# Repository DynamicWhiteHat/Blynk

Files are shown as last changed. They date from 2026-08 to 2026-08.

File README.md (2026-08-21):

# Blynk
A feature-rich LED controller

> [!NOTE]
> This board runs on [WLED firmware](https://kno.wled.ge/)

## Features:
- Powered by an ESP32 S3
- ICS-43434 microphone
- Plus line-in with ES7243
- Low-profile PIR for motion detection
- IR receiver with custom remote control
- BH1750 ambient light sensor
- Full RGBW CCT support
- Reverse polarity protection and automatic supply switching

## Image Gallery:
<table align="center">
  <tr>
    <td align="center">
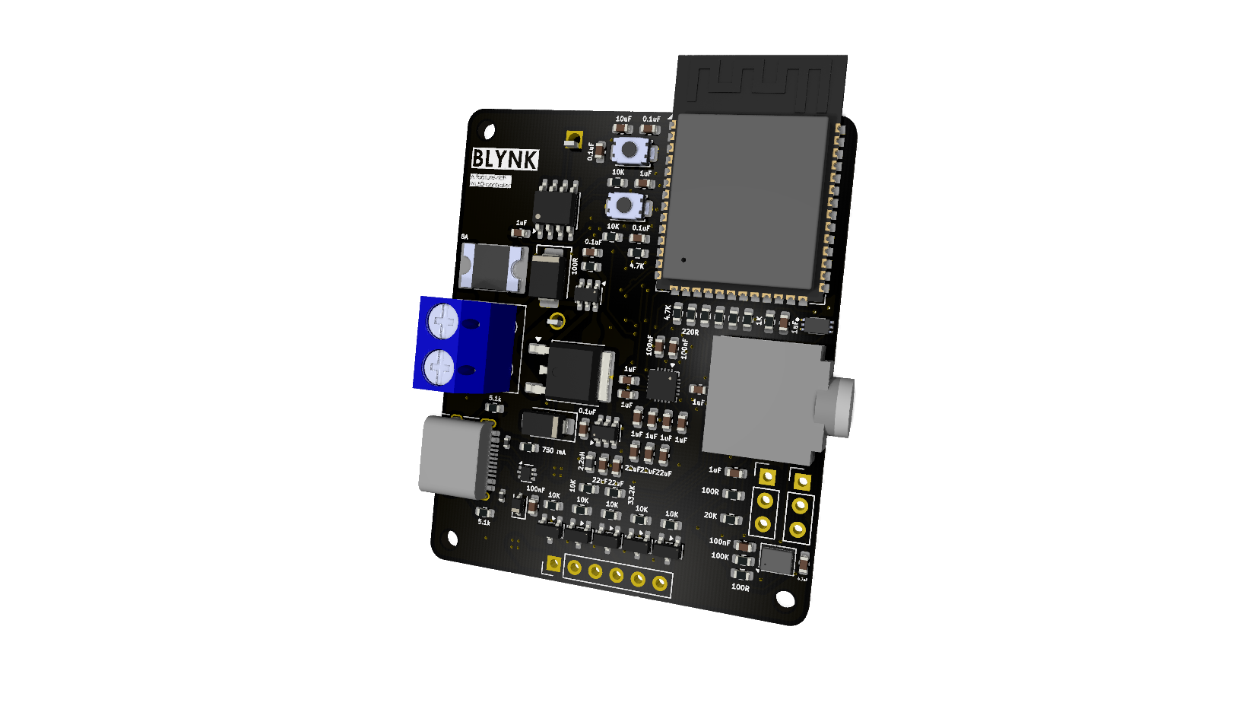
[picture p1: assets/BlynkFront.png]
      
    </td>
    <td align="center">
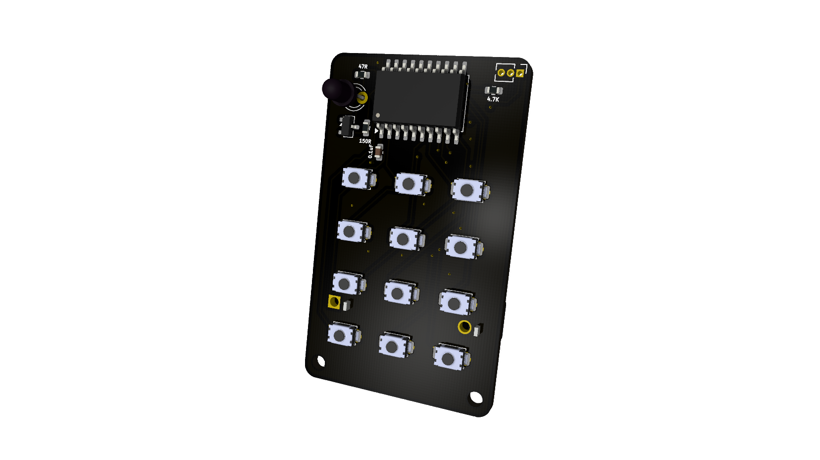
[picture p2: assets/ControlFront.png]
      
    </td>
  </tr>
  <tr>
    <td align="center" colspan="2">
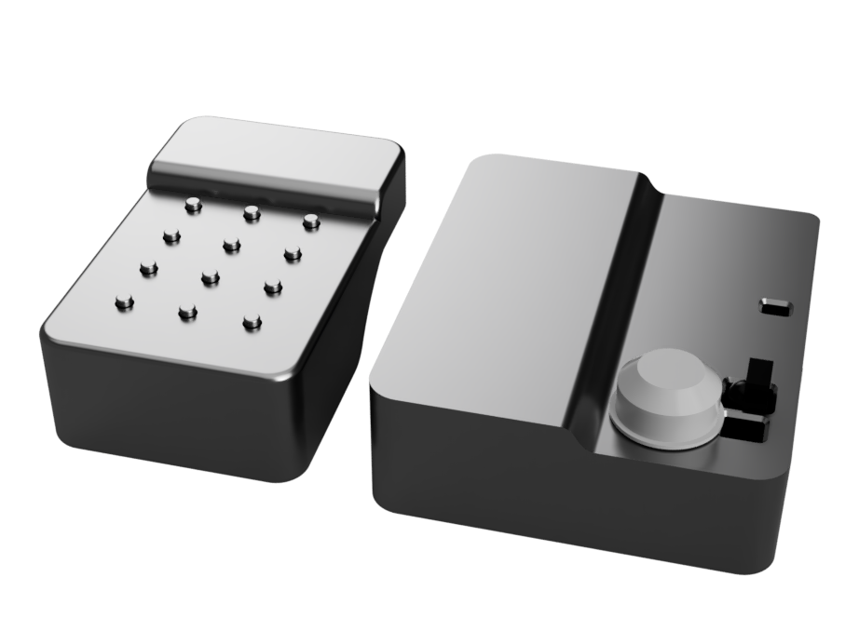
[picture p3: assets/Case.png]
      
    </td>
  </tr>
</table>

## Why I Designed This Project:
I began this project because I am getting a new large table built in my room and would love some LED lighting under it. I decided to make myself an LED controller with a lot of features. Most importantly, I wanted to have it be compatible with Alexa to match the other lights in my room. After a quick search, I found that the WLED firmware accomplishes all that I want: it is feature-rich, Alexa compatible, and supports custom ESP32 boards. And so, I embarked on a quest to make the most feature-packed LED controller to exist.

## Schematics And PCBs:
<table align="center">
  <tr>
    <td align="center" colspan="2">
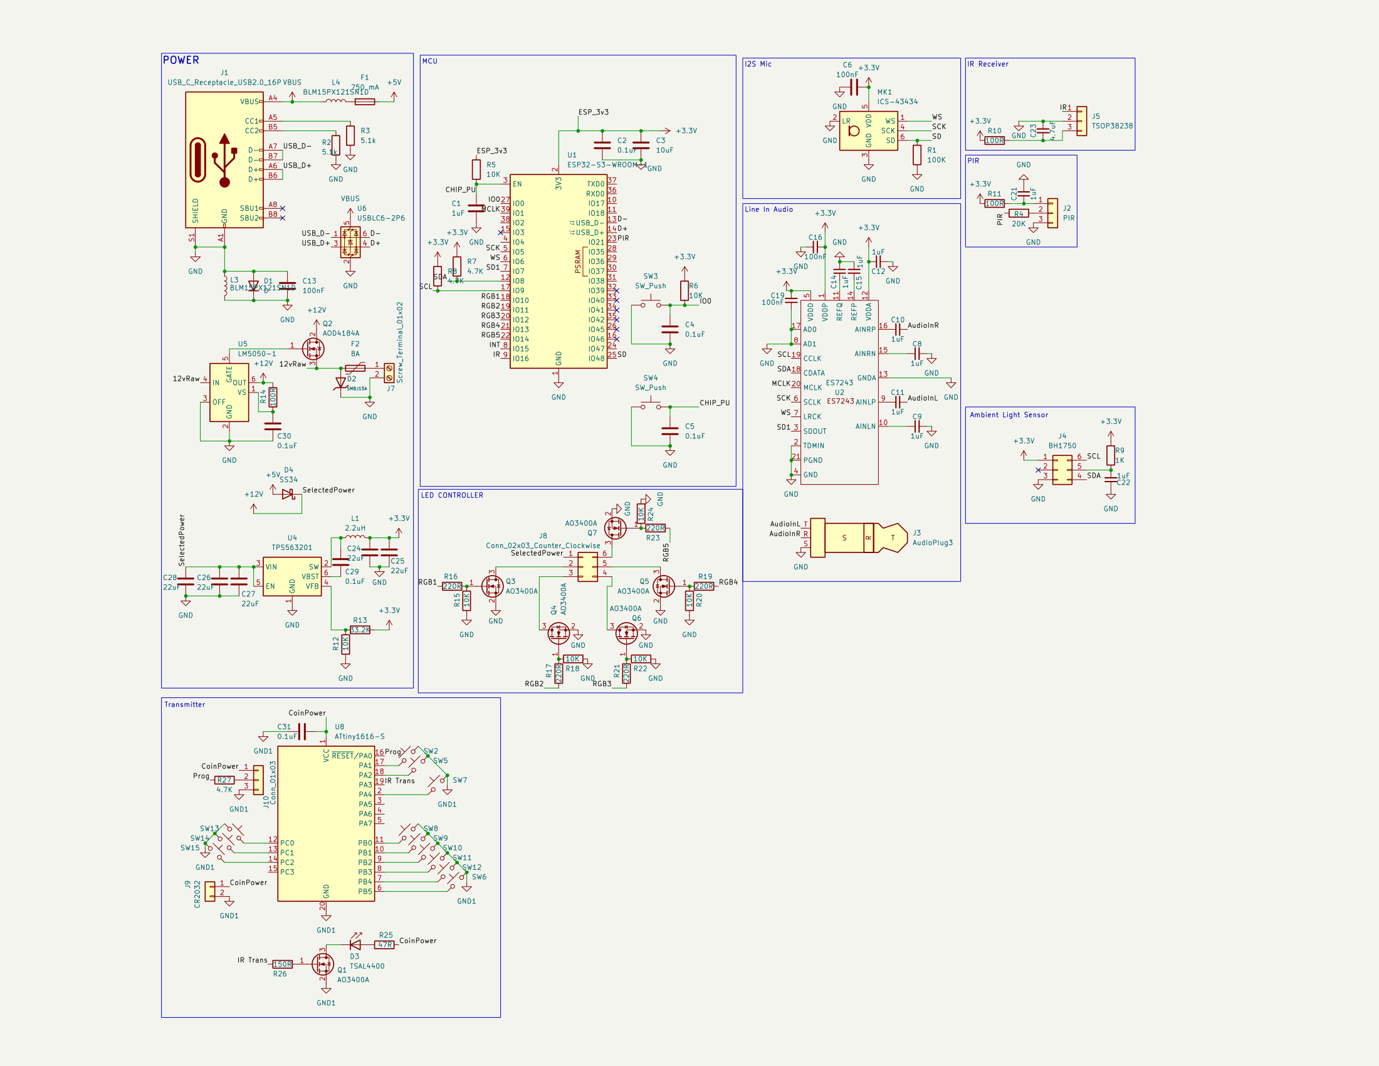
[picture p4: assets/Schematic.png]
      
    </td>
  </tr>
  <tr>
     <td align="center">
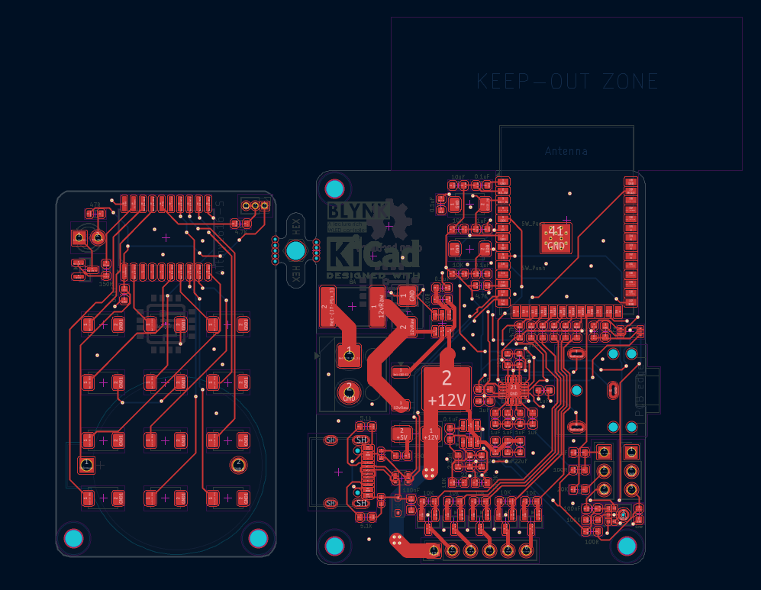
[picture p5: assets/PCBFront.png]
      
    </td>
    <td align="center">
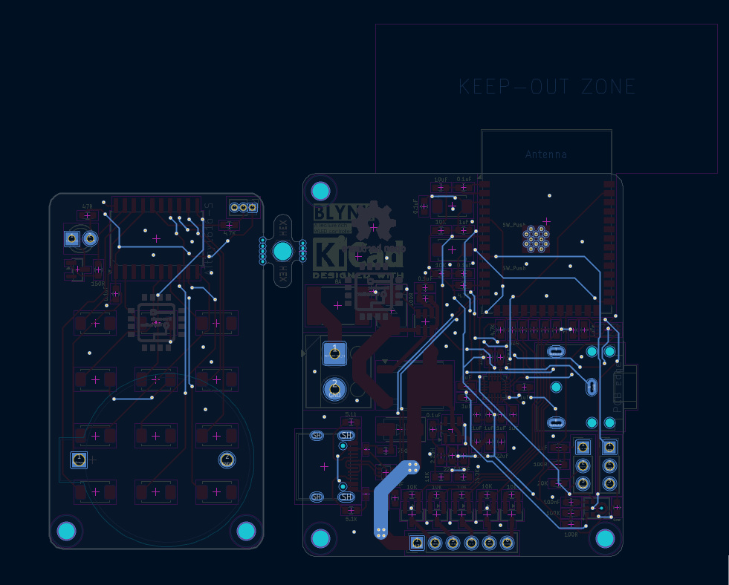
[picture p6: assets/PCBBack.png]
      
    </td>
  </tr>
</table>

## Usage:
Follow the instructions on the [WLED getting started page](https://kno.wled.ge/basics/getting-started/) after assembling your PCB to get it running.

## BOM:
|Part |Quantity |Price |Link | | | | |
|---|---|---|---|---|---|---|---|
|PCB+Stencil |1 |$24.07 |JLCPCB Quote | | | | |
|PCB Parts |1 |$56.25 |See Below | | | | |
|LED Strip |1 |$6.96 |https://www.aliexpress.us/item/3256808756097464.html | | | | |
|M2 Screws |1 |$5.22 |https://www.aliexpress.us/item/3256807092650644.html | | | | |
|Power Supply |1 |$13.94 |https://www.amazon.com/TOBWOLF-100V-240V-Transformer-Switching-Converter/dp/B0B1DGBVKB| | | | |
|PIR |1 |$3.48 |https://www.aliexpress.us/item/3256812509957711.html | | | | |
| |Total |$109.92 | | | | | |
|LCSC BOM | | | | | | | |
|Description |Quantity Needed|Mrf# |Minimum Order Qty. |Unit Price(USD) |Ext.Price(USD)|LCSC# |Product Link |
|0.1uF |6 |CC0603KRX7R9BB104  |50 |0.0186 |0.93 |C14663 |https://www.lcsc.com/product-detail/C14663.html |
|100K |1 |0603WAF1003T5E |100 |0.0068 |0.68 |C25803 |https://www.lcsc.com/product-detail/C25803.html |
|100R |3 |0603WAF1000T5E |100 |0.0222 |2.22 |C22775 |https://www.lcsc.com/product-detail/C22775.html |
|100nF |4 |CC0603KRX7R9BB104  |50 |0.0186 |0.93 |C14663 |https://www.lcsc.com/product-detail/C14663.html |
|10K |8 |0603WAF1002T5E |100 |0.0085 |0.85 |C25804 |https://www.lcsc.com/product-detail/C25804.html |
|10uF |1 |CL10A106MA8NRNC |20 |0.0841 |1.68 |C96446 |https://www.lcsc.com/product-detail/C96446.html |
|150R |1 |0603WAF1500T5E |100 |0.0087 |0.87 |C22808 |https://www.lcsc.com/product-detail/C22808.html |
|1K |1 |0603WAF1001T5E |100 |0.0058 |0.58 |C21190 |https://www.lcsc.com/product-detail/C21190.html |
|1uF |10 |CL10A105KB8NNNC |50 |0.0275 |1.38 |C15849 |https://www.lcsc.com/product-detail/C15849.html |
|2.2uH |1 |CMH160808B2R2MT |20 |0.0324 |0.65 |C394950  |https://www.lcsc.com/product-detail/C394950.html  |
|20K |1 |0603WAF2002T5E |100 |0.0052 |0.52 |C4184 |https://www.lcsc.com/product-detail/C4184.html |
|220R |5 |0603WAF2200T5E |100 |0.0086 |0.86 |C22962 |https://www.lcsc.com/product-detail/C22962.html |
|22uF |5 |CL10A226MQ8NRNC |20 |0.0313 |0.63 |C59461 |https://www.lcsc.com/product-detail/C59461.html |
|33.2K |1 |0603WAF3322T5E |100 |0.0034 |0.34 |C23003 |https://www.lcsc.com/product-detail/C23003.html |
|4.7K |3 |0603WAF4701T5E |100 |0.0118 |1.18 |C23162 |https://www.lcsc.com/product-detail/C23162.html |
|4.7uF |1 |CL10A475KO8NNNC |10 |0.0335 |0.34 |C19666 |https://www.lcsc.com/product-detail/C19666.html |
|47R |1 |0603WAF470JT5E |100 |0.0075 |0.75 |C23182 |https://www.lcsc.com/product-detail/C23182.html |
|5.1k |2 |0603WAF5101T5E |100 |0.0038 |0.38 |C23186 |https://www.lcsc.com/product-detail/C23186.html |
|750 mA |1 |BSMD0603-075-6V |10 |0.0672 |0.67 |C914092  |https://www.lcsc.com/product-detail/C914092.html  |
|8A |1 |BSMD2920L-1000-24V |1 |0.634 |0.63 |C48392676|https://www.lcsc.com/product-detail/C48392676.html|
|AO3400A |6 |AO3400A |10 |0.0849 |0.85 |C20917 |https://www.lcsc.com/product-detail/C20917.html |
|AOD4184A |1 |AOD4184A |5 |0.3474 |1.74 |C99124 |https://www.lcsc.com/product-detail/C99124.html |
|ATtiny1616-S |1 |ATTINY1616-SN |1 |2.9131 |2.91 |C614136  |https://www.lcsc.com/product-detail/C614136.html  |
|AudioPlug3 |1 |SJ1-3523N |1 |0.8493 |0.85 |C20182914|https://www.lcsc.com/product-detail/C20182914.html|
|BH1750 |1 |BH1750FVI-TR |1 |0.9687 |0.97 |C78960 |https://www.lcsc.com/product-detail/C78960.html |
|BLM15PX121SN1D |2 |BLM15PX121SN1D11 |50 |0.0097 |0.49 |C882964  |https://www.lcsc.com/product-detail/C882964.html  |
|CR2032 |1 |BS-07-A1BJ001 |5 |0.379 |1.9 |C2979167 |https://www.lcsc.com/product-detail/C2979167.html |
|D |1 |BSD3C051V |10 |0.0661 |0.66 |C151996  |https://www.lcsc.com/product-detail/C151996.html  |
|ES7243 |1 |ES7243E |1 |0.5557 |0.56 |C2929446 |https://www.lcsc.com/product-detail/C2929446.html |
|ESP32-S3-WROOM-1 |1 |ESP32-S3-WROOM-1-N8|1 |4.91 |4.91 |C2913198 |https://www.lcsc.com/product-detail/C2913198.html |
|ICS-43434 |1 |ICS-43434 |1 |3.8207 |3.82 |C5656610 |https://www.lcsc.com/product-detail/C5656610.html |
|LM5050-1 |1 |LM5050MK-1/NOPB |1 |1.1867 |1.19 |C129323  |https://www.lcsc.com/product-detail/C129323.html  |
|SMBJ15A |1 |SMBJ15A |5 |0.0539 |0.27 |C19077569|https://www.lcsc.com/product-detail/C19077569.html|
|SS34 |1 |SS34 |20 |0.0352 |0.7 |C8678 |https://www.lcsc.com/product-detail/C8678.html |
|SW_Push |2 |TS-1088-AR02016 |10 |0.0529 |0.53 |C720477  |https://www.lcsc.com/product-detail/C720477.html  |
|SW_Push_45deg |12 |TS-1088-AR02016 |20 |0.0529 |1.06 |C720477  |https://www.lcsc.com/product-detail/C720477.html  |
|Screw_Terminal_01x02 |1 |KF126-5.0-2P |5 |0.0844 |0.42 |C474900  |https://www.lcsc.com/product-detail/C474900.html  |
|TPS563201 |1 |TPS563201DDCR |10 |0.0769 |0.77 |C116592  |https://www.lcsc.com/product-detail/C116592.html  |
|TSAL4400 |1 |TSAL4400 |5 |0.4254 |2.13 |C94135 |https://www.lcsc.com/product-detail/C94135.html |
|TSOP38238 |1 |TSOP38238 |1 |0.7752 |0.78 |C141632  |https://www.lcsc.com/product-detail/C141632.html  |
|USBLC6-2P6 |1 |USBLC6-2P6 |5 |0.2787 |1.39 |C15999 |https://www.lcsc.com/product-detail/C15999.html |
|USB_C_Receptacle_USB2.0_16P|1 |TYPE-C-31-M-12 |5 |0.1716 |0.86 |C165948  |https://www.lcsc.com/product-detail/C165948.html  |
| | | | |Subtotal: |46.83 | | |
| | | | |Shipping: |12.76 | | |
| | | | |Total (after discount):|$56.25 | | |

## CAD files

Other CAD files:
CAD/Case/STL/MainBottom.stl
CAD/Case/STEP/MainTop.step
CAD/Case/STEP/TPU Cover.step
CAD/Case/STEP/RemoteBottom.step
CAD/Case/STEP/RemoteTop.step
CAD/Case.f3z
CAD/Case/STL/MainTop.stl
CAD/Case/STL/RemoteBottom.stl
CAD/Case/STL/RemoteTop.stl
CAD/Case/STL/TPU Cover.stl

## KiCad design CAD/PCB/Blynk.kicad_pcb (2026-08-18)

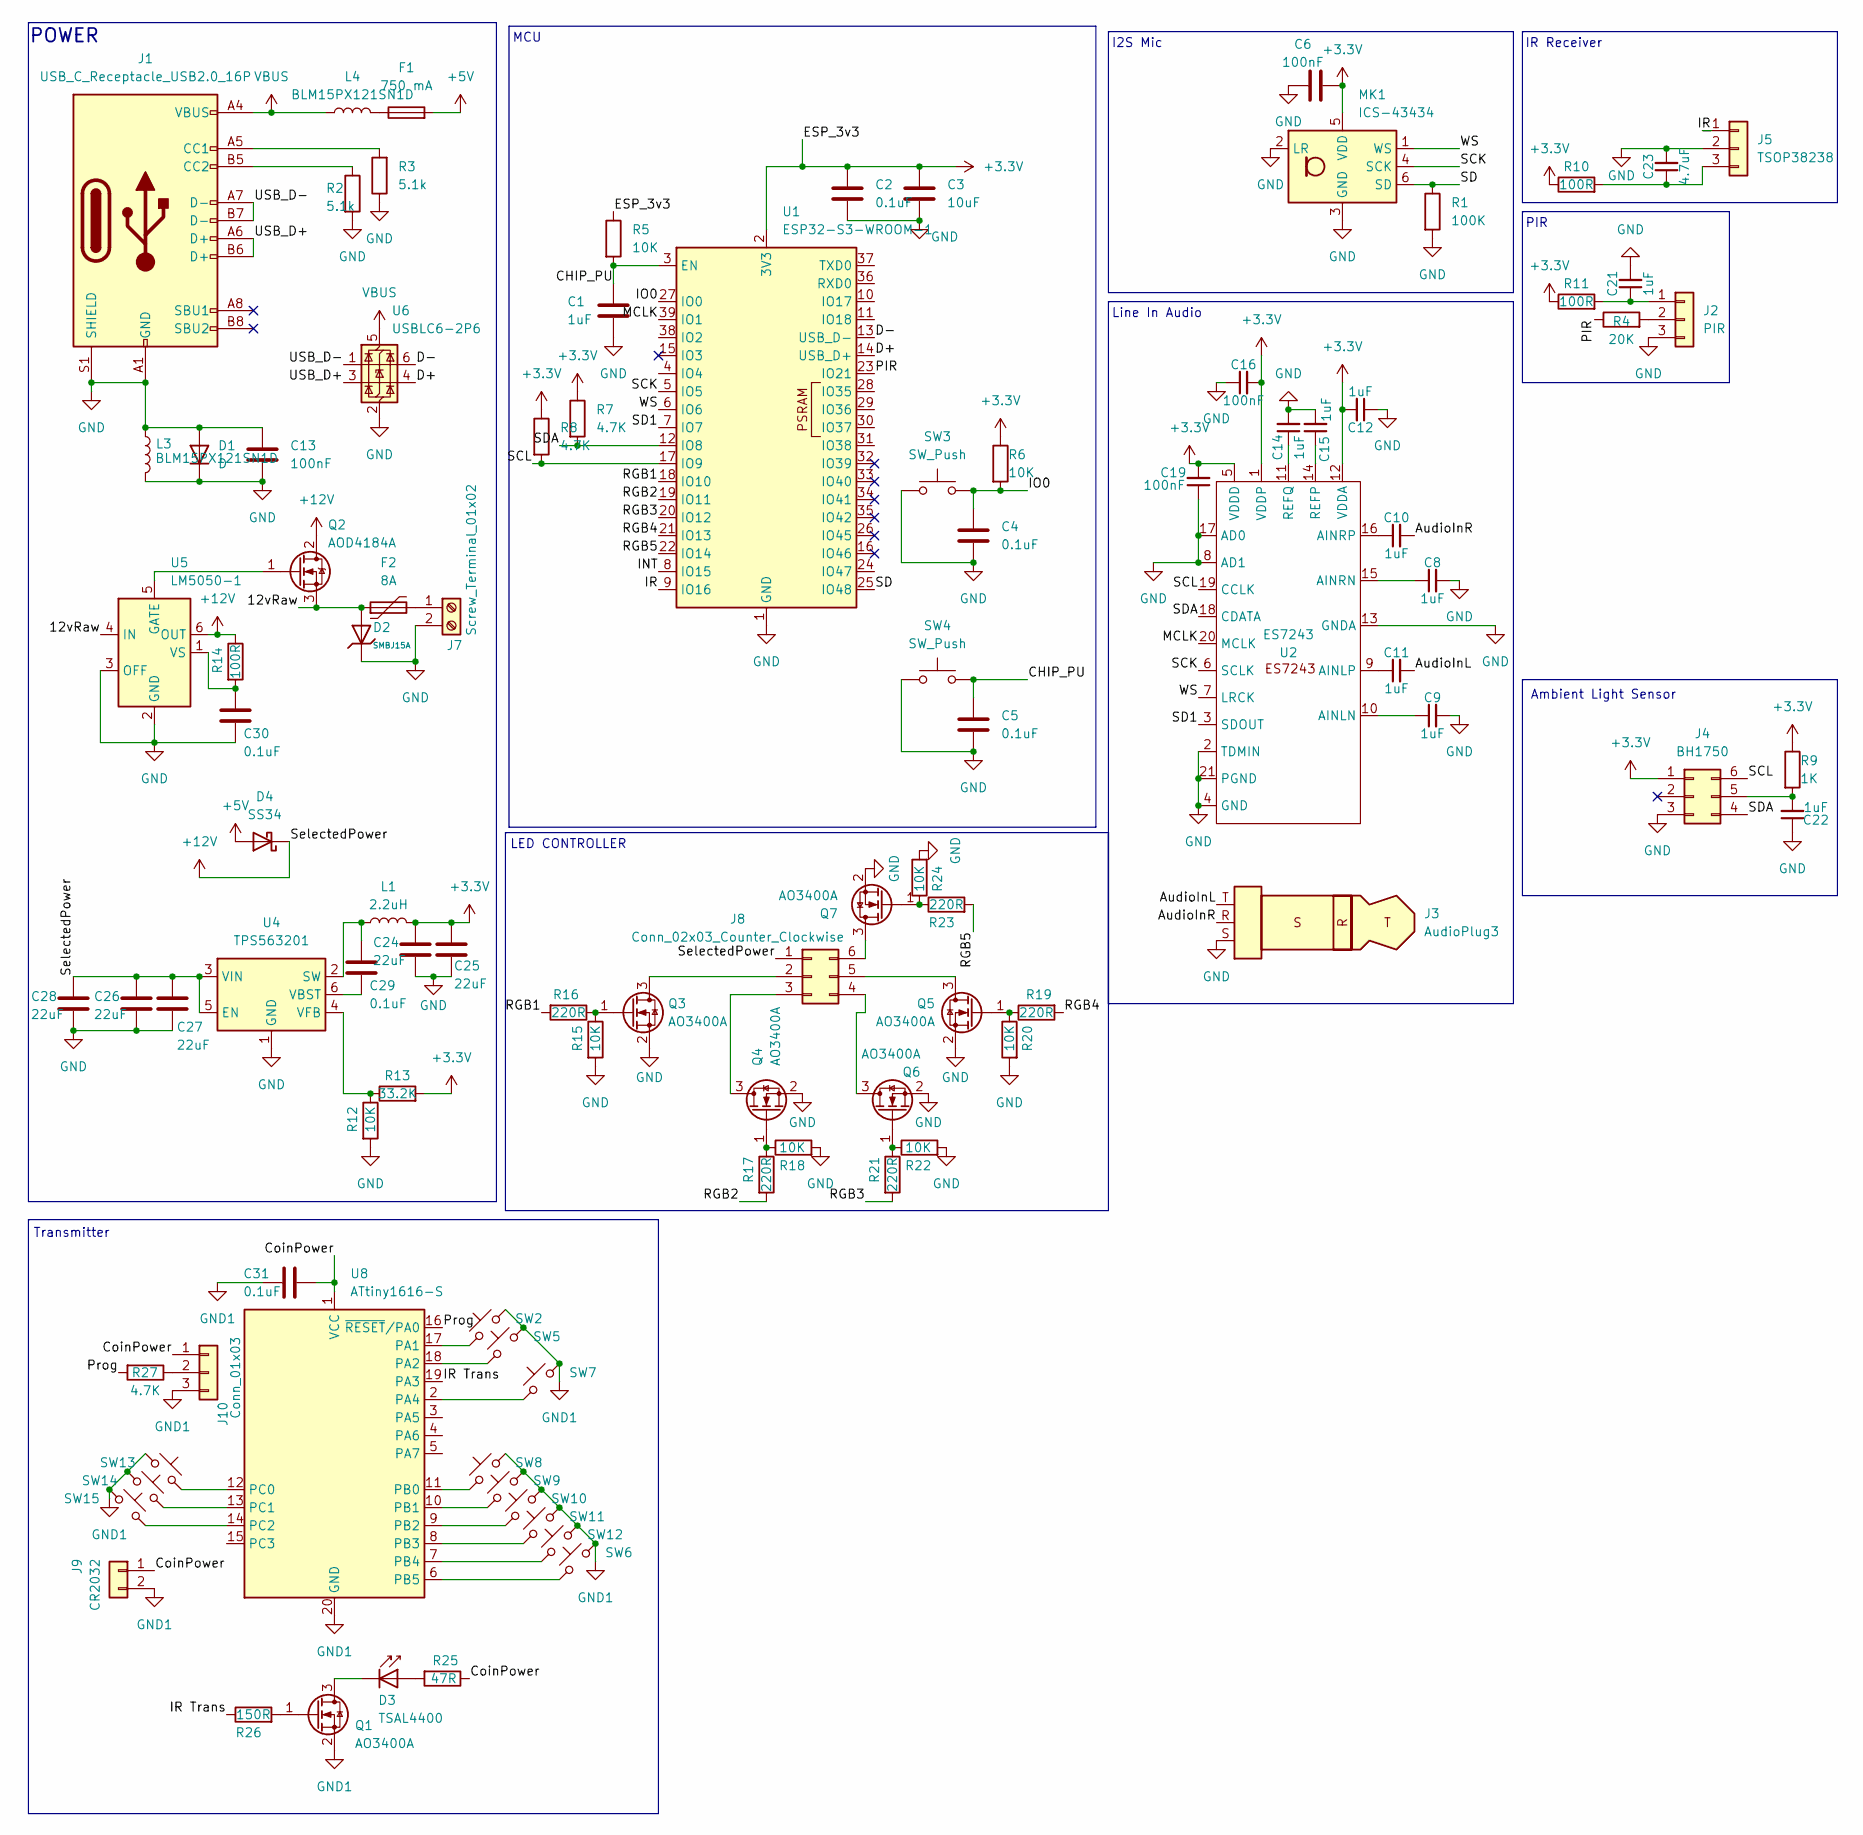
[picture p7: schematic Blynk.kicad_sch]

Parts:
C1, C8, C9, C10, C11, C12, C14, C15, C21, C22: 1uF; C_0603_1608Metric
C2, C4, C5, C29, C30, C31: 0.1uF; C_0603_1608Metric
C3: 10uF; C_0603_1608Metric
C6, C13, C16, C19: 100nF; C_0603_1608Metric
C23: 4.7uF; C_0603_1608Metric
C24, C25, C26, C27, C28: 22uF; C_0603_1608Metric
D1: D; D_SOD-323
D2: SMBJ15A; D_SMB; Part SMBJ15A; LCSC C19077569
D3: TSAL4400; LED_D3.0mm_IRBlack
D4: SS34; D_SMA
F1: 750 mA; Fuse_0603_1608Metric
F2: 8A; Fuse_2920_7451Metric
J1: USB_C_Receptacle_USB2.0_16P; USB_C_Receptacle_HRO_TYPE-C-31-M-12
J2: PIR; PinHeader_1x03_P2.54mm_Vertical
J3: AudioPlug3; Jack_3.5mm_CUI_SJ1-3523N_Horizontal
J4: BH1750; XDCR_BH1750FVI-TR
J5: TSOP38238; PinHeader_1x03_P2.54mm_Vertical
J7: Screw_Terminal_01x02; Altech_AK100_1x02_P5.00mm
J8: Conn_02x03_Counter_Clockwise; PinHeader_1x06_P2.54mm_Vertical
J9: CR2032; BatteryHolder_MYOUNG_BS-07-A1BJ001_CR2032
J10: Conn_01x03; PinHeader_1x03_P1.27mm_Vertical
L1: 2.2uH; L_0603_1608Metric
L3, L4: BLM15PX121SN1D; L_0402_1005Metric
MK1: ICS-43434; InvenSense_ICS-43434-6_3.5x2.65mm
Q1, Q3, Q4, Q5, Q6, Q7: AO3400A; SOT-23
Q2: AOD4184A; TO-252-2
R1: 100K; R_0603_1608Metric
R2, R3: 5.1k; R_0603_1608Metric
R4: 20K; R_0603_1608Metric
R5, R6, R12, R15, R18, R20, R22, R24: 10K; R_0603_1608Metric
R7, R8, R27: 4.7K; R_0603_1608Metric
R9: 1K; R_0603_1608Metric
R10, R11, R14: 100R; R_0603_1608Metric
R13: 33.2K; R_0603_1608Metric
R16, R17, R19, R21, R23: 220R; R_0603_1608Metric
R25: 47R; R_0603_1608Metric
R26: 150R; R_0603_1608Metric
SW2, SW5, SW6, SW7, SW8, SW9, SW10, SW11, SW12, SW13, SW14, SW15: SW_Push_45deg; SW_TS-1088-AR02016
SW3, SW4: SW_Push; SW_TS-1088-AR02016
U1: ESP32-S3-WROOM-1
U2: ES7243; QFN-20-1EP_3x3mm_P0.4mm_EP1.65x1.65mm
U4: TPS563201; SOT-23-6
U5: LM5050-1; TSOT-23-6
U6: USBLC6-2P6; SOT-666
U8: ATtiny1616-S; SOIC-20W_7.5x12.8mm_P1.27mm

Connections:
+3.3V: C2.1, C3.1, C6.2, C12.2, C16.2, C19.2, C24.1, C25.1, J4.1, L1.2, MK1.5 (VDD), R5.1, R6.1, R7.1, R8.1, R9.1, R10.1, R11.1, R13.2, U1.2 (3V3), U2.1 (VDDP), U2.5 (VDDD), U2.12 (VDDA)
+5V: D4.2 (A), F1.2
+12V: C26.1, C27.1, C28.1, D4.1 (K), J8.1, Q2.2 (D), R14.1, U4.3 (VIN), U4.5 (EN), U5.6 (OUT)
/12vRaw: D2.2, F2.1, Q2.3 (S), U5.4 (IN)
/AudioInL: C11.2, J3.T
/AudioInR: C10.2, J3.R
/CHIP_PU: C1.1, C5.1, R5.2, SW4.2, U1.3 (EN)
/CoinPower: C31.1, J9.1, J10.1, R25.1, U8.1 (VCC)
/D+: U1.14 (USB_D+), U6.4 (I/O2)
/D-: U1.13 (USB_D-), U6.6 (I/O1)
/INT: U1.8 (IO15)
/IO0: C4.1, R6.2, SW3.2, U1.27 (IO0)
/IR: J5.1, U1.9 (IO16)
/IR Trans: R26.1, U8.19 (PA3)
/MCLK: U1.39 (IO1), U2.20 (MCLK)
/PIR: R4.1, U1.23 (IO21)
/Prog: R27.2, U8.16 (~RESET/PA0)
/RGB1: R16.2, U1.18 (IO10)
/RGB2: R17.2, U1.19 (IO11)
/RGB3: R21.2, U1.20 (IO12)
/RGB4: R19.2, U1.21 (IO13)
/RGB5: R23.2, U1.22 (IO14)
/SCK: MK1.4 (SCK), U1.5 (IO5), U2.6 (SCLK)
/SCL: J4.6, R8.2, U1.17 (IO9), U2.19 (CCLK)
/SD: MK1.6 (SD), R1.1, U1.25 (IO48)
/SD1: U1.7 (IO7), U2.3 (SDOUT)
/SDA: J4.4, R7.2, U1.12 (IO8), U2.18 (CDATA)
/USB_D+: J1.A6 (D+), J1.B6 (D+), U6.3 (I/O2)
/USB_D-: J1.A7 (D-), J1.B7 (D-), U6.1 (I/O1)
/WS: MK1.1 (WS), U1.6 (IO6), U2.7 (LRCK)
GND: C1.2, C2.2, C3.2, C4.2, C5.2, C6.1, C8.2, C9.2, C12.1, C13.1, C13.2, C14.2, C15.2, C16.1, C19.1, C21.2, C22.1, C23.2, C24.2, C25.2, C26.2, C27.2, C28.2, C30.2, D1.1 (K), D1.2 (A), D2.1, J1.A1 (GND), J1.A12 (GND), J1.B1 (GND), J1.B12 (GND), J1.S1 (SHIELD), J2.3, J3.S, J4.3, J5.2, J7.2, L3.1, L3.2, MK1.2 (LR), MK1.3 (GND), Q3.2 (S), Q4.2 (S), Q5.2 (S), Q6.2 (S), Q7.2 (S), R1.2, R2.2, R3.1, R12.2, R15.2, R18.2, R20.2, R22.2, R24.2, SW3.1, SW4.1, U1.1 (GND), U1.40 (GND), U1.41 (GND), U2.2 (TDMIN), U2.4 (GND), U2.8 (AD1), U2.13 (GNDA), U2.17 (AD0), U2.21 (PGND), U4.1 (GND), U5.2 (GND), U5.3 (OFF), U6.2 (GND)
GND1: C31.2, J9.2, J10.3, Q1.2 (S), SW2.2, SW5.2, SW6.2, SW7.2, SW8.2, SW9.2, SW10.2, SW11.2, SW12.2, SW13.2, SW14.2, SW15.2, U8.20 (GND)
unnamed: D3.2 (A), R25.2
unnamed: D3.1 (K), Q1.3 (D)
unnamed: F1.1, L4.2
unnamed: J1.A5 (CC1), R3.2
unnamed: J1.B5 (CC2), R2.1
unnamed: C21.1, J2.1, R11.2
unnamed: J2.2, R4.2
unnamed: C22.2, J4.5, R9.2
unnamed: C23.1, J5.3, R10.2
unnamed: F2.2, J7.1
unnamed: J8.2, Q3.3 (D)
unnamed: J8.3, Q4.3 (D)
unnamed: J8.4, Q6.3 (D)
unnamed: J8.5, Q5.3 (D)
unnamed: J8.6, Q7.3 (D)
unnamed: J10.2, R27.1
unnamed: Q1.1 (G), R26.2
unnamed: Q2.1 (G), U5.5 (GATE)
unnamed: Q3.1 (G), R15.1, R16.1
unnamed: Q4.1 (G), R17.1, R18.1
unnamed: Q5.1 (G), R19.1, R20.1
unnamed: Q6.1 (G), R21.1, R22.1
unnamed: Q7.1 (G), R23.1, R24.1
unnamed: C9.1, U2.10 (AINLN)
unnamed: C11.1, U2.9 (AINLP)
unnamed: C8.1, U2.15 (AINRN)
unnamed: C10.1, U2.16 (AINRP)
unnamed: C15.1, U2.14 (REFP)
unnamed: C14.1, U2.11 (REFQ)
unnamed: C29.1, L1.1, U4.2 (SW)
unnamed: C29.2, U4.6 (VBST)
unnamed: R12.1, R13.1, U4.4 (VFB)
unnamed: C30.1, R14.2, U5.1 (VS)
unnamed: SW2.1, U8.17 (PA1)
unnamed: SW5.1, U8.18 (PA2)
unnamed: SW7.1, U8.2 (PA4)
unnamed: SW8.1, U8.11 (PB0)
unnamed: SW9.1, U8.10 (PB1)
unnamed: SW10.1, U8.9 (PB2)
unnamed: SW11.1, U8.8 (PB3)
unnamed: SW12.1, U8.7 (PB4)
unnamed: SW6.1, U8.6 (PB5)
unnamed: SW13.1, U8.12 (PC0)
unnamed: SW14.1, U8.13 (PC1)
unnamed: SW15.1, U8.14 (PC2)
VBUS: J1.A4 (VBUS), J1.A9 (VBUS), J1.B4 (VBUS), J1.B9 (VBUS), L4.1, U6.5 (VBUS)

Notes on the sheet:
Ambient Light Sensor
LED CONTROLLER
Line In Audio
MCU
POWER
Transmitter
PIR
I2S Mic
IR Receiver

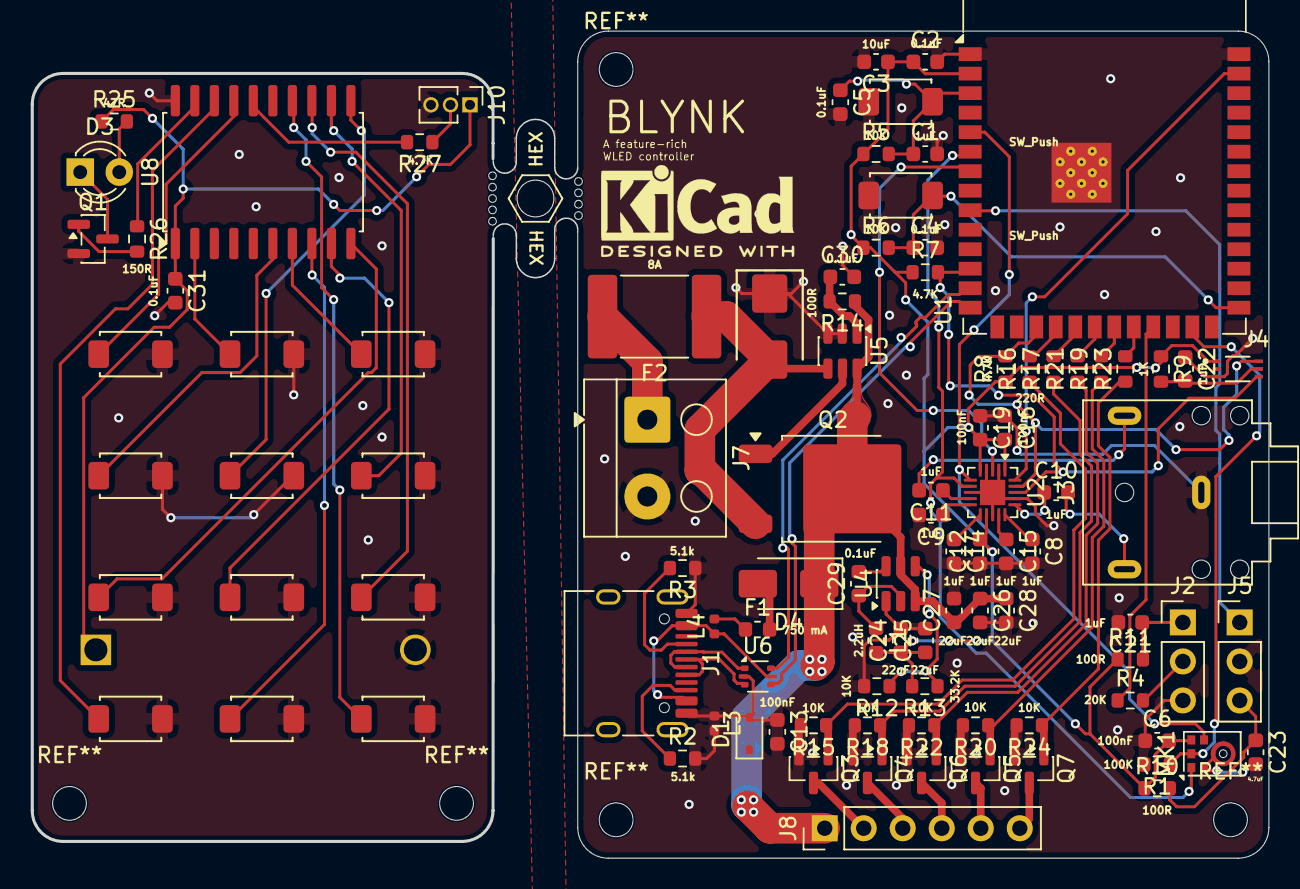
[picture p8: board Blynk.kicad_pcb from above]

Board: 2 copper layers, 80.5 x 53.8 mm, 101 parts (1 on the bottom side), 77 nets.

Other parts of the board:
MB5: 5.5mm; mousebites_5p5mm_easysnap

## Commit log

2026-08-13 Rename Blynk BOM - Sheet1.csv to BOM.csv
    [BOM.csv]
2026-08-13 Finished Repo
    [BOM-Blynk.csv, BOM.csv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]
2026-08-13 Added CAD
2026-08-13 Added CAD using lfs
2026-08-18 Added PCB Files
    [Blynk.kicad_pcb, Blynk.kicad_sch]
2026-08-21 Update BOM with new PCB Stencil price
    Updated PCB Stencil price and total cost in BOM.
2026-08-21 Modify BOM.csv with updated parts and costs
    Updated BOM with new prices and quantities.
    [BOM.csv]
